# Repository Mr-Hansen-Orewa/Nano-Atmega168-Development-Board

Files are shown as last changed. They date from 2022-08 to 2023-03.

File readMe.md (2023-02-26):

# Read Me

## Overview
I am designing a development board for year 11 students (15-16 year olds) to use in 2023

## Parts list
- Arduino Nano with Atmega168 controller 
- Yellow LED
- RGB LED
- Trimpot
- LDR
- 3 switch DIP switch
- Button

## Pinout and Headers
 - D0 - goes to a header.
 - D1 - goes to a header.
 - D2 - momentary switch.
 - D3 - goes to a header.
 - D4 - DIP switch 1.
 - D5 - goes to a header.
 - D6 - goes to a header.
 - D7 - DIP switch 2.
 - D8 - DIP switch 3.
 - D9 - RGB LED Blue/Green (silkscreen issues).
 - D10 - RGB LED Blue/Green (silkscreen issues).
 - D11 - RGB LED Red.
 - D12 - goes to a header.
 - D13 - Yellow LED.
 - D14/A0 - LDR.
 - D15/A1 - trimpot.
 - D16/A2 - goes to a header.
 - D17/A3 - goes to a header.
 - D18/A4 - goes to a header.
 - D19/A5 - goes to a header.
 - A6 - goes to a header.
 - A7 - goes to a header.

## Cool bits
I used the import bmp script in the automate menu to put the logo on the silkscreen. 

I also put a testpoint rectangle in the tStop layer to leave it as exposed copper for a GND testpoint.

## Future ideas/versions
Have a qwiic / stemmaQT connector on the I2C pins its a JST SH 4-pin Vertical Connector on Adafruit.
Or have an led matrix board directly soldered to the I2C pins.
Or another button without the debounce resistor - maybe both buttons have resistors but also those PCB jumper solder pads to enable or disable them once shown button bounce issues.
https://youtu.be/uOp_2-7_1Hw.

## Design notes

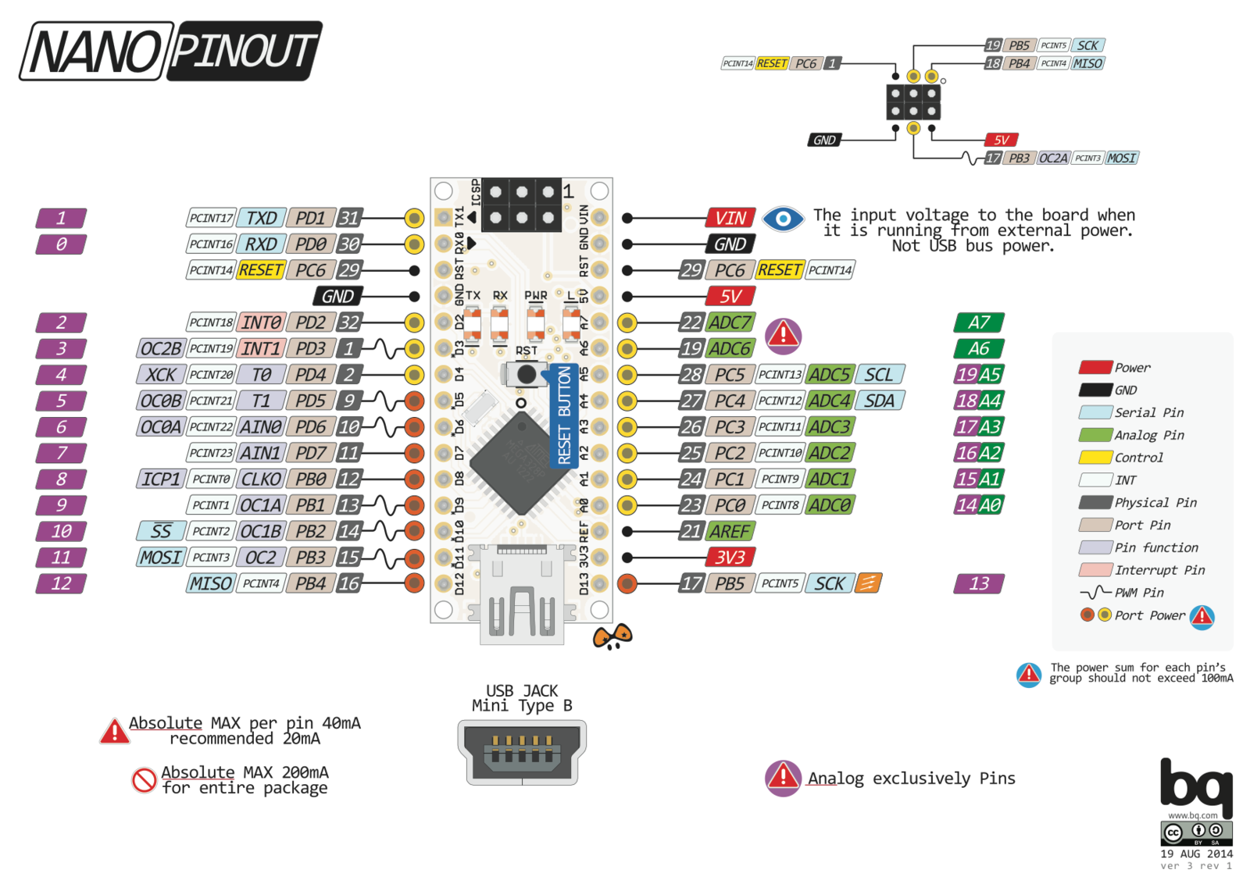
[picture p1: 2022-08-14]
Images/Arduino-nano-pinout-1600px.png

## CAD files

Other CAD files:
Hardware/Electronics Design v34.f3z

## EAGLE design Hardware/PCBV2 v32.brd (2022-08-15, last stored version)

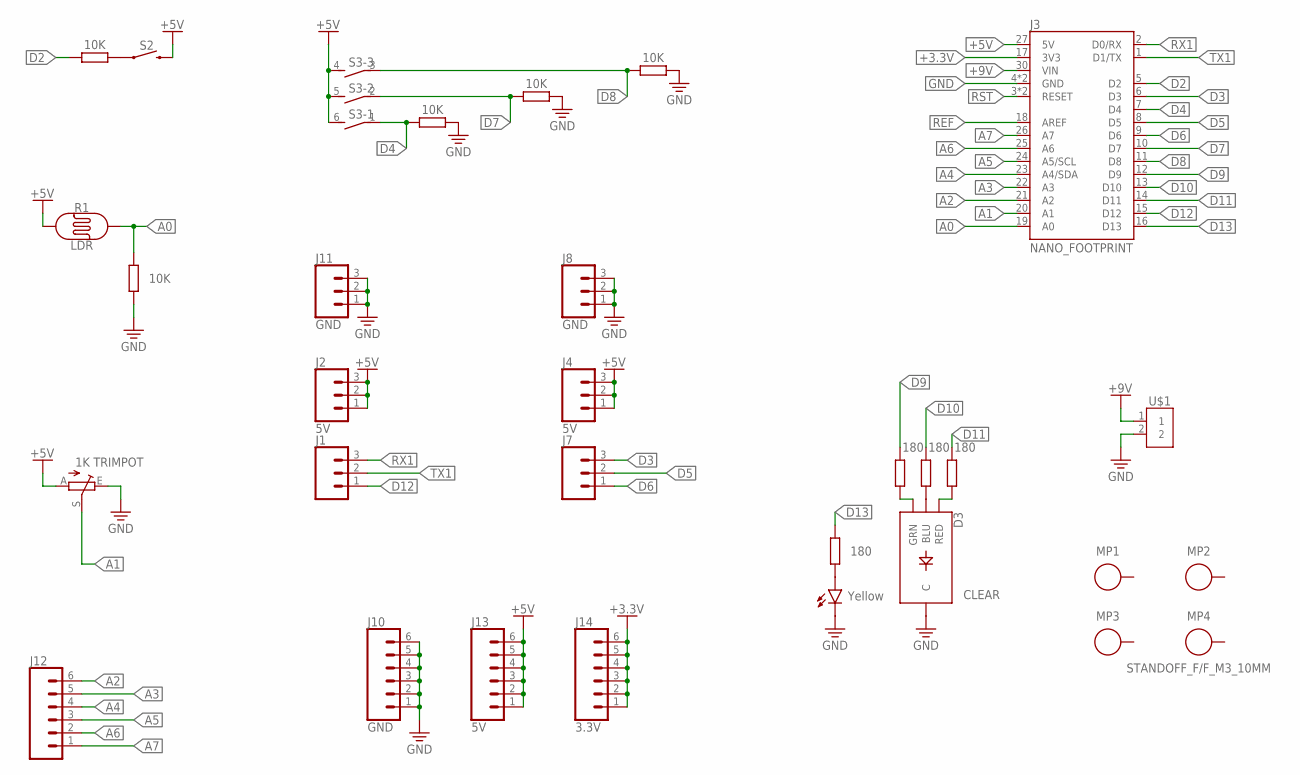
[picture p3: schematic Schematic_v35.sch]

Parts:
D2: Yellow; LED_5MM
D3: CLEAR; LED-RGB-THRU
J1, J7: CONN_03; 1X03
J2, J4: 5V; 1X03
J3: NANO_FOOTPRINT; NANO
J8, J11: GND; 1X03
J10: GND; 1X06
J12: CONN_06SILK_FEMALE_PTH; 1X06
J13: 5V; 1X06
J14: 3.3V; 1X06
MP1, MP2, MP3, MP4: STANDOFF_F/F_M3_10MM; STANDOFF_HEX_FEMALE_550X1000_M3X0.5_MTGP850H320
R1: LDR; PHOTOCELL-KIT
R3, R6, R7, R8: 180; RESAD724W46L381D178B
R4: 1K TRIMPOT; B25P
R5, R9, R10, R11, R12: 10K; RESAD724W46L381D178B
S2: BUTTON; TACTILE_SWITCH_PTH_6.0MM_KIT
S3: DIP SWITCH; DS-03
U$1: 2828XX-2282837-2; TERMBLK_508-2N

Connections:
+3.3V: J3.17 (3V3), J14.1, J14.2, J14.3, J14.4, J14.5, J14.6
+5V: J2.1, J2.2, J2.3, J3.27 (5V), J4.1, J4.2, J4.3, J13.1, J13.2, J13.3, J13.4, J13.5, J13.6, R1.1, R4.A, S2.3 (2), S3.4 (2), S3.5 (2), S3.6 (2)
+9V: J3.30 (VIN), U$1.1
A0: J3.19 (A0), R1.2, R9.2
A1: J3.20 (A1), R4.S
A2: J3.21 (A2), J12.6
A3: J3.22 (A3), J12.5
A4: J3.23 (A4/SDA), J12.4
A5: J3.24 (A5/SCL), J12.3
A6: J3.25 (A6), J12.2
A7: J3.26 (A7), J12.1
D2: J3.5 (D2), R5.2
D3: J3.6 (D3), J7.3
D4: J3.7 (D4), R12.2, S3.1
D5: J3.8 (D5), J7.2
D6: J3.9 (D6), J7.1
D7: J3.10 (D7), R11.2, S3.2 (1)
D8: J3.11 (D8), R10.2, S3.3 (1)
D9: J3.12 (D9), R6.2
D10: J3.13 (D10), R7.2
D11: J3.14 (D11), R8.2
D12: J1.1, J3.15 (D12)
D13: J3.16 (D13), R3.2
GND: D2.K (C), D3.2 (C), J3.4 (GND), J3.29 (GND), J8.1, J8.2, J8.3, J10.1, J10.2, J10.3, J10.4, J10.5, J10.6, J11.1, J11.2, J11.3, R4.E, R9.1, R10.1, R11.1, R12.1, U$1.2
unnamed: D2.A, R3.1
unnamed: D3.3 (GRN), R6.1
unnamed: R5.1, S2.1
unnamed: D3.4 (BLU), R7.1
unnamed: D3.1 (RED), R8.1
REF: J3.18 (AREF)
RST: J3.3 (RESET), J3.28 (RESET)
RX1: J1.3, J3.2 (D0/RX)
TX1: J1.2, J3.1 (D1/TX)

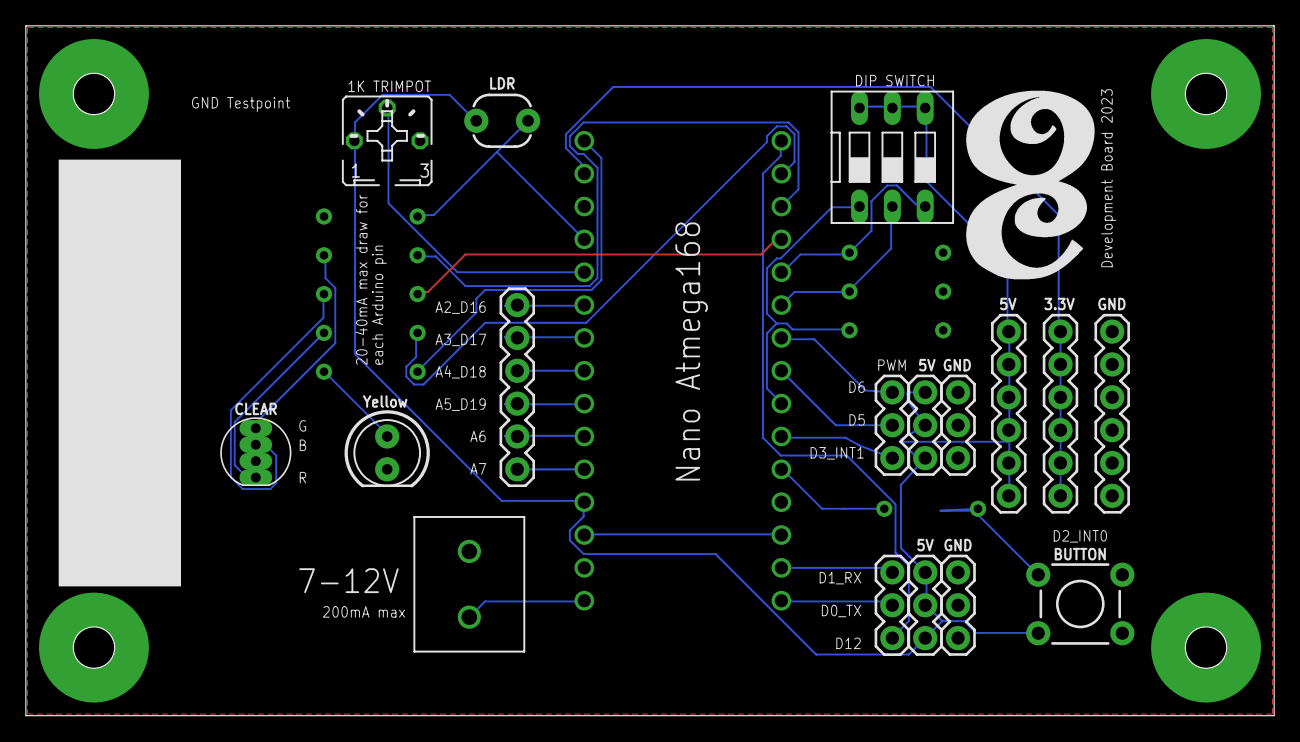
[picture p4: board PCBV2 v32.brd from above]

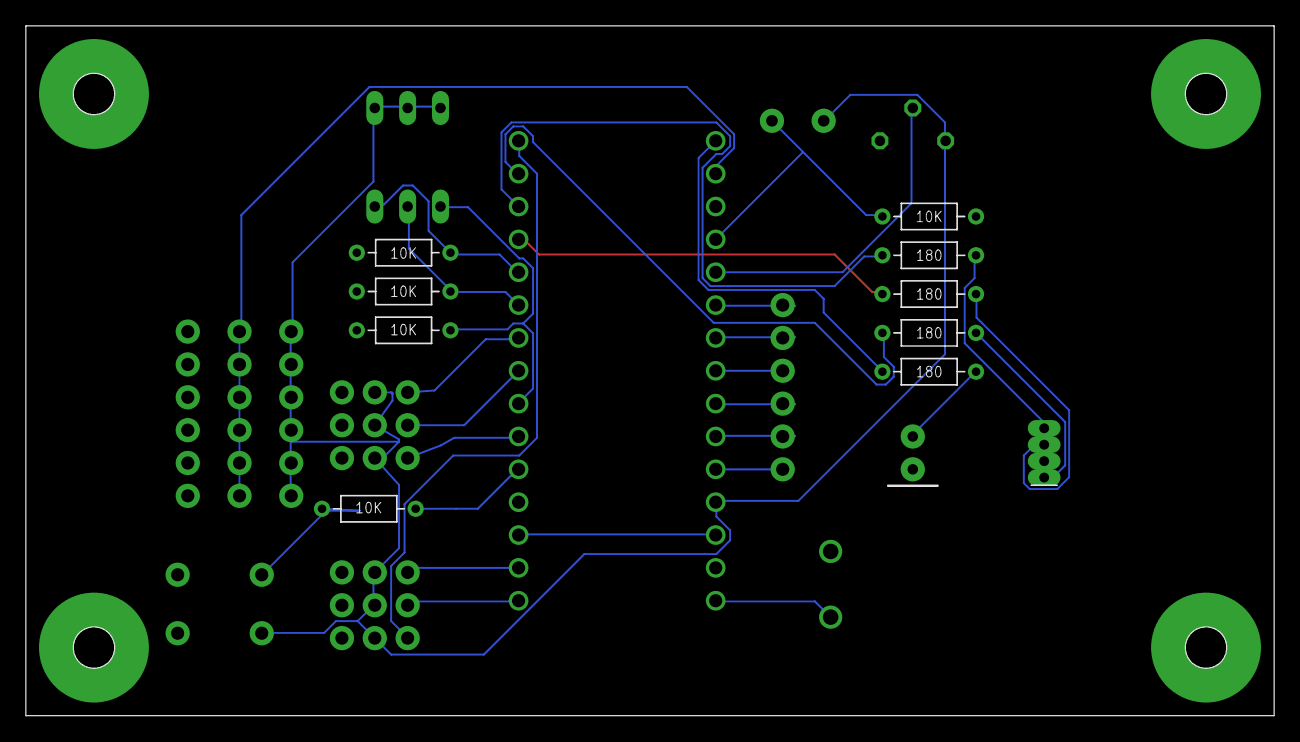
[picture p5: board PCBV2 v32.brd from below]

Board: 2 copper layers, 96.5 x 53.3 mm, 31 parts (13 on the bottom side), 32 nets.

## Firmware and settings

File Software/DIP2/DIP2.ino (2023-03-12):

//ID 12345

const byte BUTTONPIN = 2;
const byte DIP1PIN = 8;
const byte DIP2PIN = 7;
const byte DIP3PIN = 4;
const byte RLEDPIN = 9;
const byte GLEDPIN = 10;
const byte BLEDPIN = 11;

void setup() {
  pinMode(BUTTONPIN, INPUT);
  pinMode(DIP1PIN, INPUT);
  pinMode(DIP2PIN, INPUT);
  pinMode(DIP3PIN, INPUT);
  pinMode(RLEDPIN, OUTPUT);
  pinMode(GLEDPIN, OUTPUT);
  pinMode(BLEDPIN, OUTPUT);

  Serial.begin(9600);
}

void loop() {
  if (digitalRead(BUTTONPIN) == HIGH) {
    checkDIP();
  }
  delay(250);
}

void checkDIP() {
  byte decimalVal = 0;
  if (digitalRead(DIP1PIN) == HIGH) {
    decimalVal = decimalVal + 4;
  }
  if (digitalRead(DIP2PIN) == HIGH) {
    decimalVal = decimalVal + 2;
  }
  if (digitalRead(DIP3PIN) == HIGH) {
    decimalVal = decimalVal + 1;
  }
  Serial.print("DIP value in decimal is ");
  Serial.println(decimalVal);

  switch (decimalVal) {
    case 0:
      digitalWrite(RLEDPIN, LOW);
      digitalWrite(GLEDPIN, LOW);
      digitalWrite(BLEDPIN, LOW);
      Serial.println("RGB off");
      break;
    case 1:
      digitalWrite(RLEDPIN, HIGH);
      digitalWrite(GLEDPIN, LOW);
      digitalWrite(BLEDPIN, LOW);
      Serial.println("R on, GB off");
      break;
    case 2:
      digitalWrite(RLEDPIN, LOW);
      digitalWrite(GLEDPIN, HIGH);
      digitalWrite(BLEDPIN, LOW);
      Serial.println("G on, RB off");
      break;
    case 3:
      digitalWrite(RLEDPIN, HIGH);
      digitalWrite(GLEDPIN, HIGH);
      digitalWrite(BLEDPIN, LOW);
      Serial.println("RG on, B off");
      break;
    case 4:
      digitalWrite(RLEDPIN, LOW);
      digitalWrite(GLEDPIN, LOW);
      digitalWrite(BLEDPIN, HIGH);
      Serial.println("B on, RG off");
      break;
    case 5:
      digitalWrite(RLEDPIN, HIGH);
      digitalWrite(GLEDPIN, LOW);
      digitalWrite(BLEDPIN, HIGH);
      Serial.println("RB on, G off");
      break;
    case 6:
      digitalWrite(RLEDPIN, LOW);
      digitalWrite(GLEDPIN, HIGH);
      digitalWrite(BLEDPIN, HIGH);
      Serial.println("GB on, R off");
      break;
    case 7:
      digitalWrite(RLEDPIN, HIGH);
      digitalWrite(GLEDPIN, HIGH);
      digitalWrite(BLEDPIN, HIGH);
      Serial.println("RGB on");
      break;
    default:
      Serial.println("ERROR");
      break;
  }
}

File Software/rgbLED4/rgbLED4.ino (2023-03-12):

//ID 12345
#include <LibPrintf.h>;

const byte BUTTONPIN = 2;
const byte POTPIN = A1;
const byte RLEDPIN = 9;
const byte GLEDPIN = 10;
const byte BLEDPIN = 11;

byte colorChoice = 2; //0=R 1=G 2=B
byte rLedVal = 127;
byte gLedVal = 127;
byte bLedVal = 127;

void setup() {
  pinMode(BUTTONPIN, INPUT);
  pinMode(POTPIN, INPUT);
  pinMode(RLEDPIN, OUTPUT);
  pinMode(GLEDPIN, OUTPUT);
  pinMode(BLEDPIN, OUTPUT);

  Serial.begin(9600);
}

/*Take the pot value and save to rLedVal or similar

  trimpot val read when button is clicked and saved to variable
  flash the RGB to say where it was saved

  then turn RGB led back on with new values
*/
void loop() {
  int PotVal = analogRead(POTPIN);
  PotVal = map(PotVal, 0, 1023, 0, 255);
  printf("PotVal is %i\n", PotVal);

  if (digitalRead(BUTTONPIN) == HIGH) {
    colorChoice++;
    switch (colorChoice) {
      case 0:
        rLedVal = PotVal;
        flashRGB(RLEDPIN);
        break;
      case 1:
        gLedVal = PotVal;
        flashRGB(GLEDPIN);
        break;
      case 2:
        bLedVal = PotVal;
        flashRGB(BLEDPIN);
        colorChoice = 0; //reset to R once done
        break;
      default:
        Serial.println("ERROR");
        break;
    }
  }
  analogWrite(RLEDPIN, rLedVal);
  analogWrite(GLEDPIN, gLedVal);
  analogWrite(BLEDPIN, bLedVal);
  printf("RGB values are R%i, G%i, B%i\n", rLedVal, gLedVal, bLedVal);
}

//flash the color of the pin given for half second
void flashRGB(byte pin) {
  digitalWrite(RLEDPIN, LOW);
  digitalWrite(GLEDPIN, LOW);
  digitalWrite(BLEDPIN, LOW);

  digitalWrite(pin, HIGH);
  delay(500);

  digitalWrite(RLEDPIN, LOW);
  digitalWrite(GLEDPIN, LOW);
  digitalWrite(BLEDPIN, LOW);
}

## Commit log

2022-08-13 Add files via upload
    Black and white bmp of the college logo
    Follow the below steps to import BMP file in Fusion 360 PCB workspace:
    Open the Fusion 360 PCB workspace.
    Go to the 2D layout file and select the Automation tab.
    Choose Run ULP option, browse and select from the list the ULP file called "import-bmp" in Fusion 360.
    Select the .bmp file from a computer location to import the file to Fusion 360.
    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
2022-08-13 Create Electronics Design v34.f3z
    added export of schematic and PCB
    [Electronics Design v34.f3z]
2022-08-15 added board files
    [Electronics Design v34.f3z, PCBV2 v32.brd, Schematic_v35.sch]
2022-08-25 changes to pcb
    updated the rgb led as pads touching
    also the silkscreen to label pins and give thicker traces
    [PCBV2 v32.brd, Schematic_v35.sch]
2023-02-26 examples added
    added basic and extension code examples that students would try and type up to test board and their programming skills
2023-03-12 added code examples
    fixed DIP added some RGB code too
    RGB4 is intended as a excellence exemplar but needs more modification and testing
    [DIP.ino, DIP2.ino, rgbLED3.ino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]
2024-01-30 Create buzzer.ino
    added a buzzer in 2024
    tone works better than digitalWrite
    [buzzer.ino]

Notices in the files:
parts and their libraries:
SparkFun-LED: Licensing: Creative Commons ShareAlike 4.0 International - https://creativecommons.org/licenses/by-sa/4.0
